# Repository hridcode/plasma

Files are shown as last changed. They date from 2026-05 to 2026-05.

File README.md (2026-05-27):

# Plasma

Plasma is an ortholinear staggered split keyboard that connects with BLE. It has an OLED display and rotary encoder as well for extra fun! With 6 columns and 5 rows, plus space keys right at the thumbs, what's not to love?

# Pictures

|Schematic (L)|Schematic (R)|PCB|Case|
|---|---|---|---|
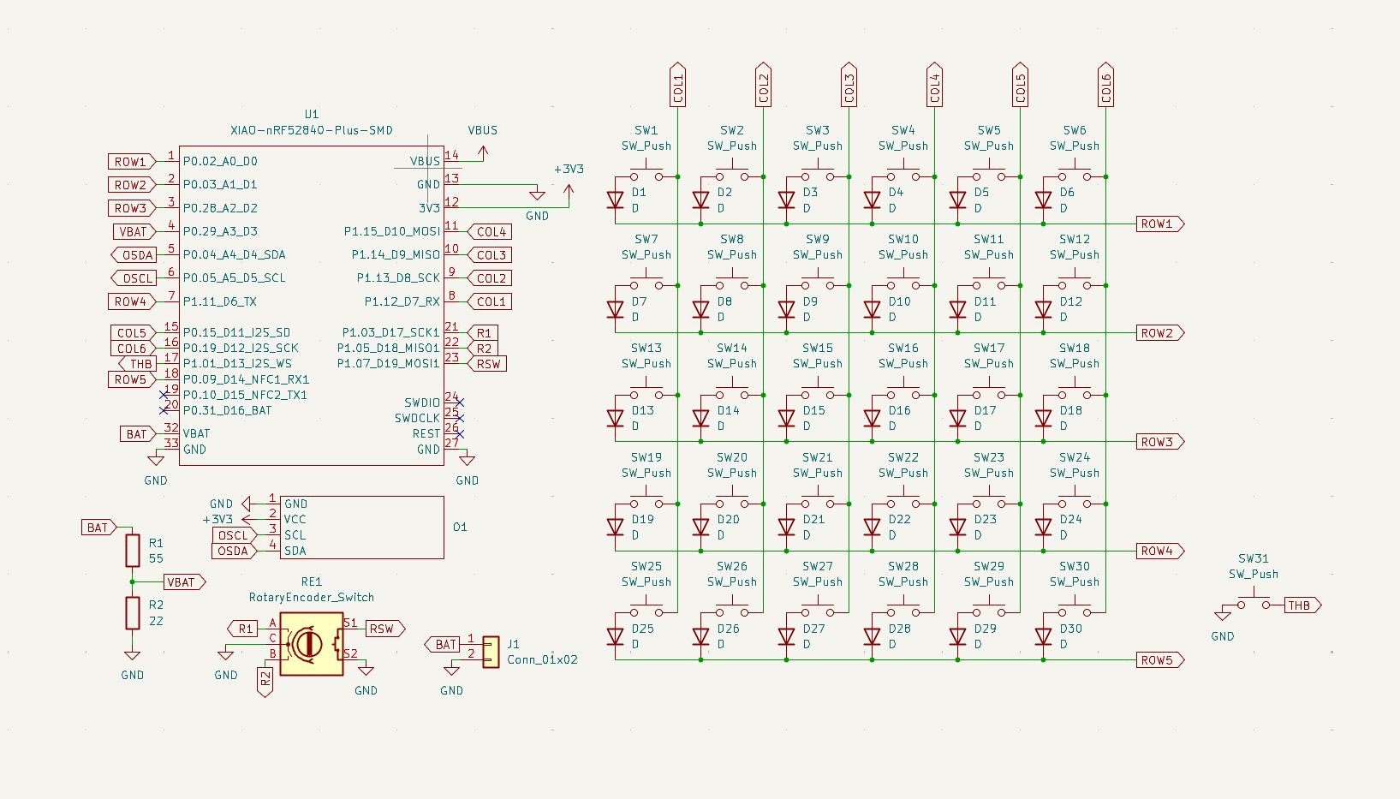
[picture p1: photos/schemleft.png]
Left schematic
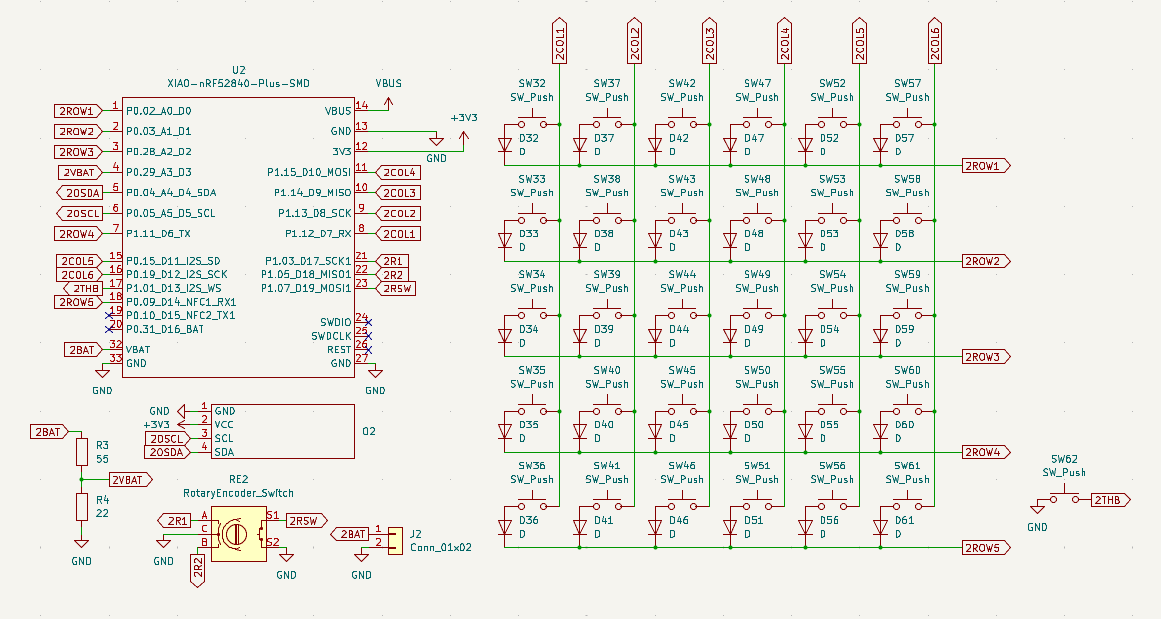
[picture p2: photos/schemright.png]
Right schematic
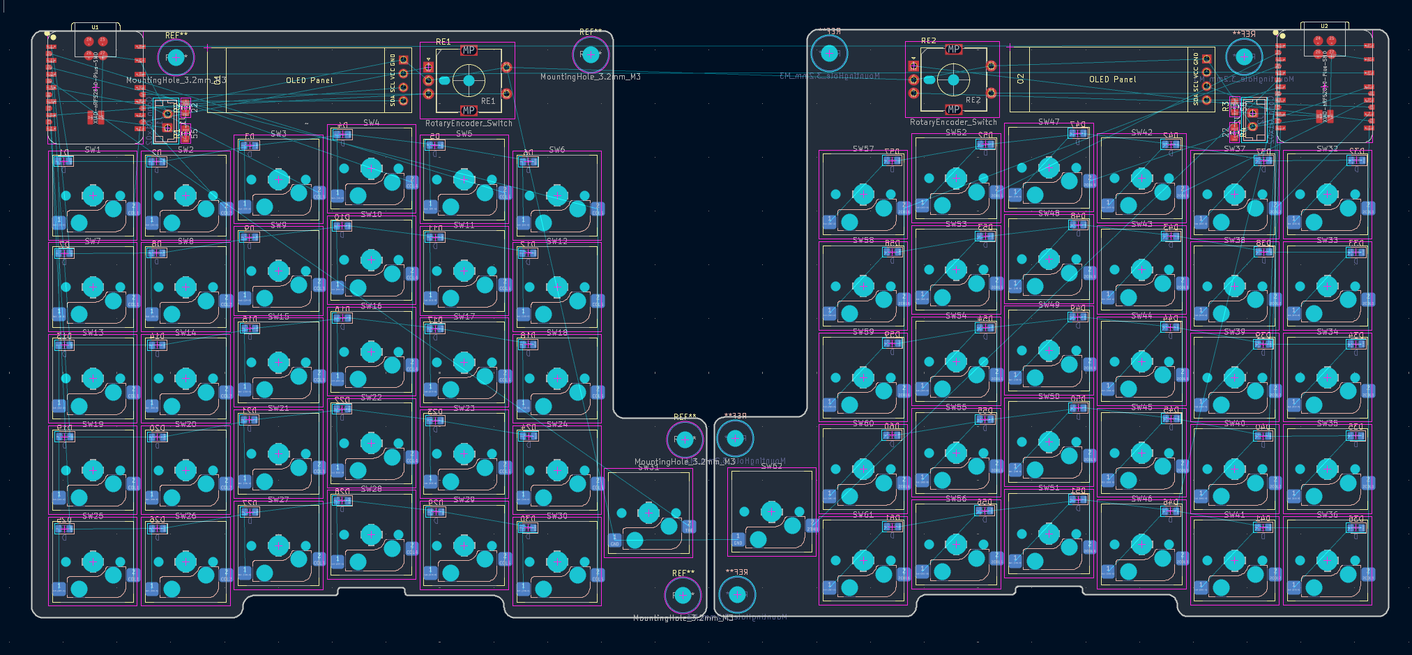
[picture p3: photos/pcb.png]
PCB
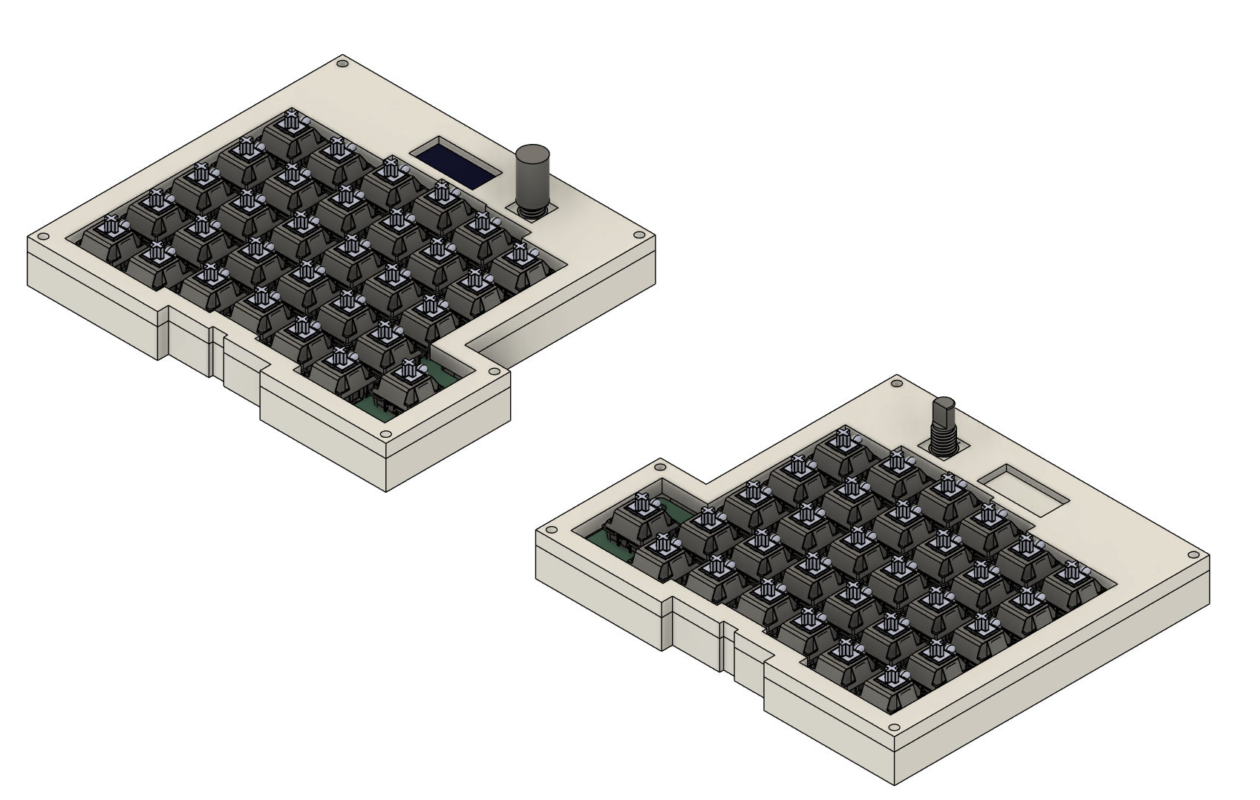
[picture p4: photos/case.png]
Case
|||||

# BOM

|Item|Quantity|Cost|Source|
|---|---|---|---|
|Seeed Studio XIAO nRF52840 Plus|2|20.80|https://www.seeedstudio.com/Seeed-Studio-XIAO-nRF52840-Plus-p-6359.html|
|Key switches|1|17.34|https://www.aliexpress.us/item/3256810602342636.html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|
YMDK ZDA black keycaps|1|16.94|https://www.aliexpress.us/item/3256808606272435.html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|
|EC11 rotary encoders|1|3.08|https://www.aliexpress.us/item/3256807457610925.html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|
|SSD1306 OLED displays|1|3.50|https://www.aliexpress.us/item/3256806882812437.html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|
|LiPo batteries|1|5.02|https://www.aliexpress.us/item/3256811857707355.html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|
|JST connectors|1|2.79|https://www.aliexpress.us/item/3256801462843682.html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|
|M3 inserts|1|0.73|https://www.aliexpress.com/ssr/300000512/BundleDeals2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|
|M3x16 screws|1|2.92|https://www.aliexpress.us/item/3256808523663879.html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|
|M3x6 screws|1|2.14|https://www.aliexpress.us/item/3256808523663879.html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|
|Hotswap sockets|1|3.89|https://www.aliexpress.com/ssr/300000512/BundleDeals2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
|PCBs|1|15.20|https://cart.jlcpcb.com/quote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|
|0805 resistors|1|6.50|https://www.aliexpress.us/item/3256805806582589.html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|
|3D printed case (from Printing Legion)|1|6.00|

Total: $120.17

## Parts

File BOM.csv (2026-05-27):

Item | Quantity | Cost | Source
Seeed Studio XIAO nRF52840 Plus | 2 | 20.80 | https://www.seeedstudio.com/Seeed-Studio-XIAO-nRF52840-Plus-p-6359.html
Key switches | 1 | 17.34 | https://www.aliexpress.us/item/3256810602342636.html?mp=1
YMDK ZDA black keycaps | 1 | 16.94 | https://www.aliexpress.us/item/3256808606272435.html?curPageLogUid=46jL7OyEjN3m
EC11 rotary encoders | 1 | 3.08 | https://www.aliexpress.us/item/3256807457610925.html?curPageLogUid=Gnz1vOJZ5LKS
SSD1306 OLED displays | 1 | 3.50 | https://www.aliexpress.us/item/3256806882812437.html?curPageLogUid=kfCFOX5XGs2T
LiPo batteries | 1 | 5.02 | https://www.aliexpress.us/item/3256811857707355.html
JST connectors | 1 | 2.79 | https://www.aliexpress.us/item/3256801462843682.html?curPageLogUid=LgkQ6isYab0G
M3 inserts | 1 | 0.73 | https://www.aliexpress.com/ssr/300000512/BundleDeals2?productIds=1005006967339727%3A12000038886016094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
M3x16 screws | 1 | 2.92 | https://www.aliexpress.us/item/3256808523663879.html?curPageLogUid=TUfYajctXH1A
M3x6 screws | 1 | 2.14 | https://www.aliexpress.us/item/3256808523663879.html?curPageLogUid=TUfYajctXH1A
Hotswap sockets | 1 | 3.89 | https://www.aliexpress.com/ssr/300000512/BundleDeals2?productIds=1005007052649640%3A12000039244942221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
PCBs | 1 | 15.20 | https://cart.jlcpcb.com/quote?stencilLayer=2&stencilWidth=253&stencilLength=110&stencilCounts=5&plateType=1
0805 SMD resistors | 1 | 6.50 | https://www.aliexpress.us/item/3256805806582589.html?curPageLogUid=6eeBEBX80vKN
3D printed case (from Printing Legion) | 1 | 6.00
Total |  | 120.17

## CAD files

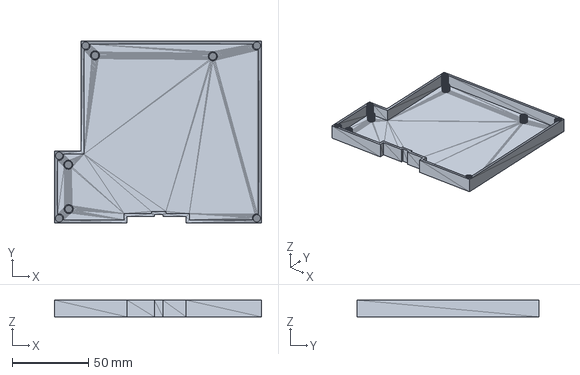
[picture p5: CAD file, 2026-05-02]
production/cad/BottomCase2.step
135.4 x 119.0 x 11.0 mm

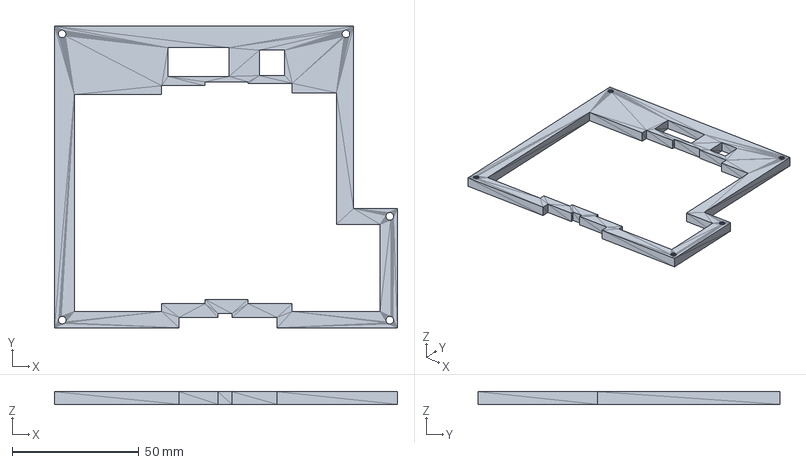
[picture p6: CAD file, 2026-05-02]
production/cad/TopCase.step
135.3 x 119.0 x 5.00 mm

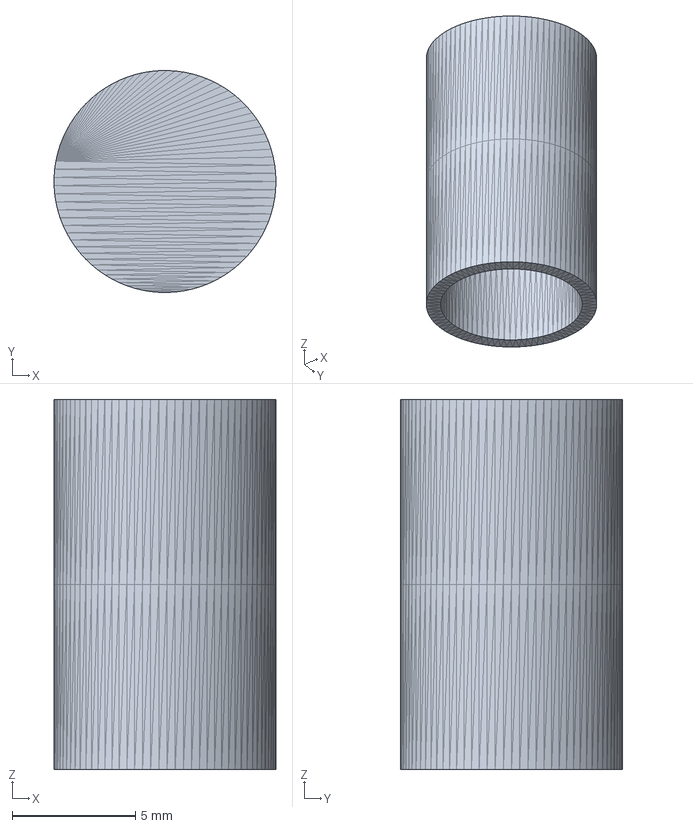
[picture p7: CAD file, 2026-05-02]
production/cad/EncoderKnob.step
9.00 x 9.00 x 15.0 mm

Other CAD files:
production/cad/BottomCase.step
production/cad/TopCase2.step

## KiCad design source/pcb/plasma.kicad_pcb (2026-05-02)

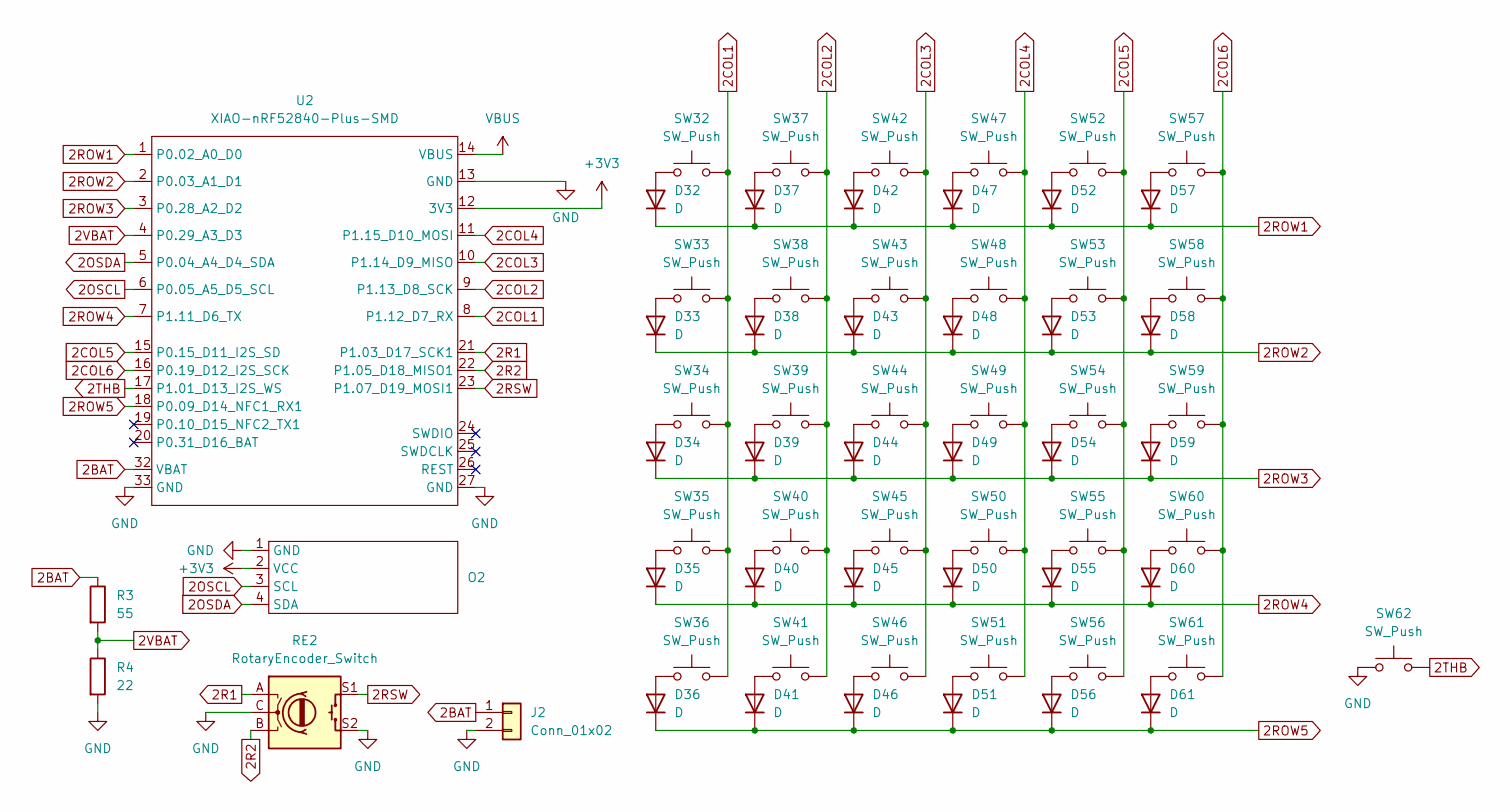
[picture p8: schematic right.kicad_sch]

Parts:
D32, D33, D34, D35, D36, D37, D38, D39, D40, D41, D42, D43, D44, D45, D46, D47, D48, D49, D50, D51, D52, D53, D54, D55, D56, D57, D58, D59, D60, D61: D; D_0805_2012Metric_Pad1.15x1.40mm_HandSolder
J2: Conn_01x02; JST_EH_B2B-EH-A_1x02_P2.50mm_Vertical
O2: SSD1306-4pin-0.91
R3: 55; R_0805_2012Metric_Pad1.20x1.40mm_HandSolder
R4: 22; R_0805_2012Metric_Pad1.20x1.40mm_HandSolder
RE2: RotaryEncoder_Switch; RotaryEncoder_Alps_EC11E-Switch_Vertical_H20mm_MountingHoles
SW32, SW33, SW34, SW35, SW36, SW37, SW38, SW39, SW40, SW41, SW42, SW43, SW44, SW45, SW46, SW47, SW48, SW49, SW50, SW51, SW52, SW53, SW54, SW55, SW56, SW57, SW58, SW59, SW60, SW61, SW62: SW_Push; SW_MX_HotSwap_THT
U2: XIAO-nRF52840-Plus-SMD

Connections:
2BAT: J2.1, R3.1, U2.32 (VBAT)
2COL1: SW32.2, SW33.2, SW34.2, SW35.2, SW36.2, U2.8 (P1.12_D7_RX)
2COL2: SW37.2, SW38.2, SW39.2, SW40.2, SW41.2, U2.9 (P1.13_D8_SCK)
2COL3: SW42.2, SW43.2, SW44.2, SW45.2, SW46.2, U2.10 (P1.14_D9_MISO)
2COL4: SW47.2, SW48.2, SW49.2, SW50.2, SW51.2, U2.11 (P1.15_D10_MOSI)
2COL5: SW52.2, SW53.2, SW54.2, SW55.2, SW56.2, U2.15 (P0.15_D11_I2S_SD)
2COL6: SW57.2, SW58.2, SW59.2, SW60.2, SW61.2, U2.16 (P0.19_D12_I2S_SCK)
2OSCL: O2.3 (SCL), U2.6 (P0.05_A5_D5_SCL)
2OSDA: O2.4 (SDA), U2.5 (P0.04_A4_D4_SDA)
2R1: RE2.A, U2.21 (P1.03_D17_SCK1)
2R2: RE2.B, U2.22 (P1.05_D18_MISO1)
2ROW1: D32.1 (K), D37.1 (K), D42.1 (K), D47.1 (K), D52.1 (K), D57.1 (K), U2.1 (P0.02_A0_D0)
2ROW2: D33.1 (K), D38.1 (K), D43.1 (K), D48.1 (K), D53.1 (K), D58.1 (K), U2.2 (P0.03_A1_D1)
2ROW3: D34.1 (K), D39.1 (K), D44.1 (K), D49.1 (K), D54.1 (K), D59.1 (K), U2.3 (P0.28_A2_D2)
2ROW4: D35.1 (K), D40.1 (K), D45.1 (K), D50.1 (K), D55.1 (K), D60.1 (K), U2.7 (P1.11_D6_TX)
2ROW5: D36.1 (K), D41.1 (K), D46.1 (K), D51.1 (K), D56.1 (K), D61.1 (K), U2.18 (P0.09_D14_NFC1_RX1)
2RSW: RE2.S1, U2.23 (P1.07_D19_MOSI1)
2THB: SW62.2, U2.17 (P1.01_D13_I2S_WS)
2VBAT: R3.2, R4.1, U2.4 (P0.29_A3_D3)
+3V3: O2.2 (VCC), U2.12 (3V3); also elsewhere on the board
GND: J2.2, O2.1 (GND), R4.2, RE2.C, RE2.S2, SW62.1, U2.13 (GND), U2.27 (GND), U2.33 (GND); also elsewhere on the board
unnamed: D32.2 (A), SW32.1
unnamed: D33.2 (A), SW33.1
unnamed: D34.2 (A), SW34.1
unnamed: D35.2 (A), SW35.1
unnamed: D36.2 (A), SW36.1
unnamed: D37.2 (A), SW37.1
unnamed: D38.2 (A), SW38.1
unnamed: D39.2 (A), SW39.1
unnamed: D40.2 (A), SW40.1
unnamed: D41.2 (A), SW41.1
unnamed: D42.2 (A), SW42.1
unnamed: D43.2 (A), SW43.1
unnamed: D44.2 (A), SW44.1
unnamed: D45.2 (A), SW45.1
unnamed: D46.2 (A), SW46.1
unnamed: D47.2 (A), SW47.1
unnamed: D48.2 (A), SW48.1
unnamed: D49.2 (A), SW49.1
unnamed: D50.2 (A), SW50.1
unnamed: D51.2 (A), SW51.1
unnamed: D52.2 (A), SW52.1
unnamed: D53.2 (A), SW53.1
unnamed: D54.2 (A), SW54.1
unnamed: D55.2 (A), SW55.1
unnamed: D56.2 (A), SW56.1
unnamed: D57.2 (A), SW57.1
unnamed: D58.2 (A), SW58.1
unnamed: D59.2 (A), SW59.1
unnamed: D60.2 (A), SW60.1
unnamed: D61.2 (A), SW61.1
VBUS: U2.14 (VBUS); also elsewhere on the board

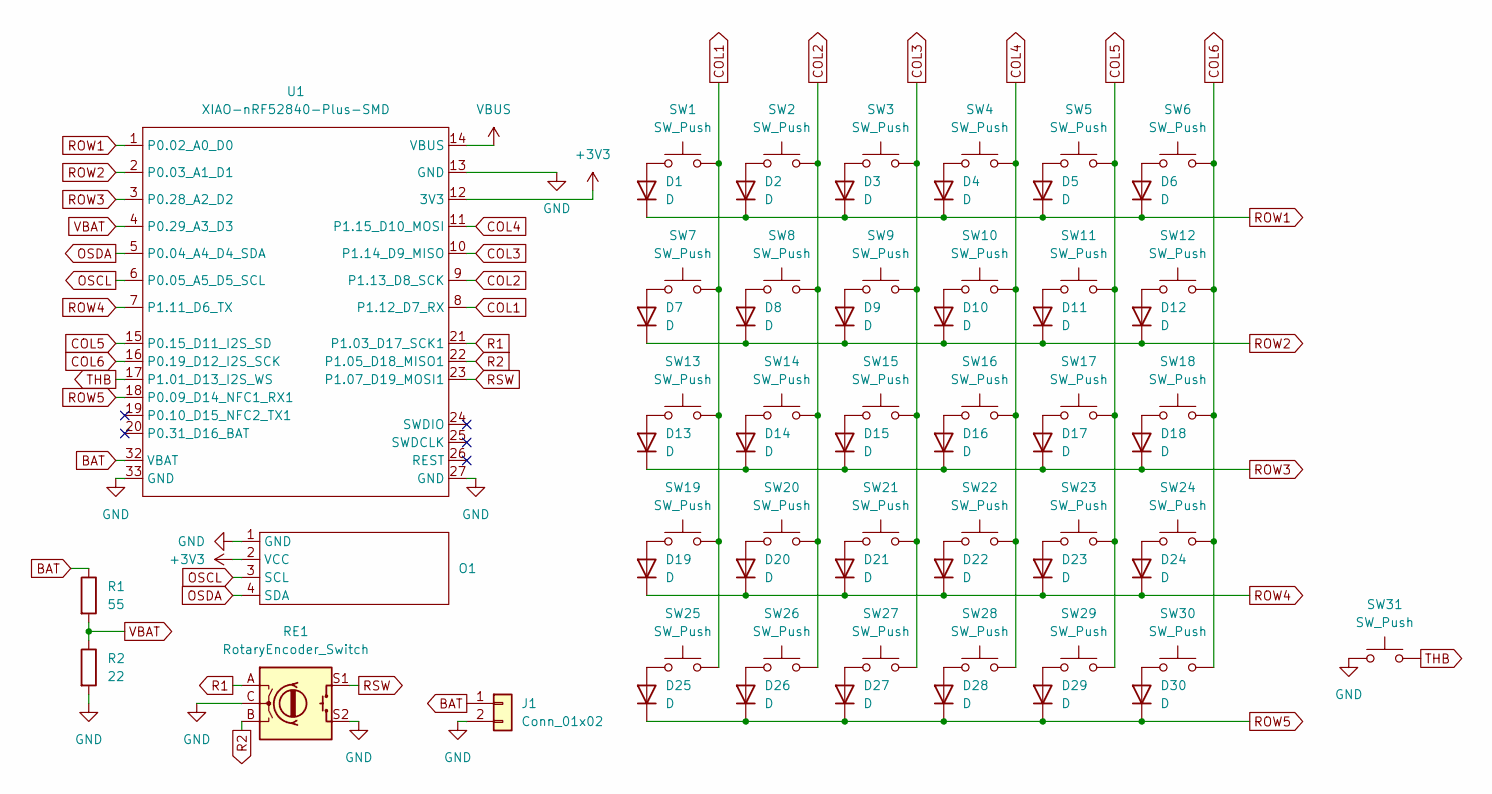
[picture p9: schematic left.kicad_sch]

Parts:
D1, D2, D3, D4, D5, D6, D7, D8, D9, D10, D11, D12, D13, D14, D15, D16, D17, D18, D19, D20, D21, D22, D23, D24, D25, D26, D27, D28, D29, D30: D; D_0805_2012Metric_Pad1.15x1.40mm_HandSolder
J1: Conn_01x02; JST_EH_B2B-EH-A_1x02_P2.50mm_Vertical
O1: SSD1306-4pin-0.91
R1: 55; R_0805_2012Metric_Pad1.20x1.40mm_HandSolder
R2: 22; R_0805_2012Metric_Pad1.20x1.40mm_HandSolder
RE1: RotaryEncoder_Switch; RotaryEncoder_Alps_EC11E-Switch_Vertical_H20mm_MountingHoles
SW1, SW2, SW3, SW4, SW5, SW6, SW7, SW8, SW9, SW10, SW11, SW12, SW13, SW14, SW15, SW16, SW17, SW18, SW19, SW20, SW21, SW22, SW23, SW24, SW25, SW26, SW27, SW28, SW29, SW30, SW31: SW_Push; SW_MX_HotSwap_THT
U1: XIAO-nRF52840-Plus-SMD

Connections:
+3V3: O1.2 (VCC), U1.12 (3V3); also elsewhere on the board
BAT: J1.1, R1.1, U1.32 (VBAT)
COL1: SW1.2, SW7.2, SW13.2, SW19.2, SW25.2, U1.8 (P1.12_D7_RX)
COL2: SW2.2, SW8.2, SW14.2, SW20.2, SW26.2, U1.9 (P1.13_D8_SCK)
COL3: SW3.2, SW9.2, SW15.2, SW21.2, SW27.2, U1.10 (P1.14_D9_MISO)
COL4: SW4.2, SW10.2, SW16.2, SW22.2, SW28.2, U1.11 (P1.15_D10_MOSI)
COL5: SW5.2, SW11.2, SW17.2, SW23.2, SW29.2, U1.15 (P0.15_D11_I2S_SD)
COL6: SW6.2, SW12.2, SW18.2, SW24.2, SW30.2, U1.16 (P0.19_D12_I2S_SCK)
GND: J1.2, O1.1 (GND), R2.2, RE1.C, RE1.S2, SW31.1, U1.13 (GND), U1.27 (GND), U1.33 (GND); also elsewhere on the board
unnamed: D1.2 (A), SW1.1
unnamed: D2.2 (A), SW2.1
unnamed: D3.2 (A), SW3.1
unnamed: D4.2 (A), SW4.1
unnamed: D5.2 (A), SW5.1
unnamed: D6.2 (A), SW6.1
unnamed: D7.2 (A), SW7.1
unnamed: D8.2 (A), SW8.1
unnamed: D9.2 (A), SW9.1
unnamed: D10.2 (A), SW10.1
unnamed: D11.2 (A), SW11.1
unnamed: D12.2 (A), SW12.1
unnamed: D13.2 (A), SW13.1
unnamed: D14.2 (A), SW14.1
unnamed: D15.2 (A), SW15.1
unnamed: D16.2 (A), SW16.1
unnamed: D17.2 (A), SW17.1
unnamed: D18.2 (A), SW18.1
unnamed: D19.2 (A), SW19.1
unnamed: D20.2 (A), SW20.1
unnamed: D21.2 (A), SW21.1
unnamed: D22.2 (A), SW22.1
unnamed: D23.2 (A), SW23.1
unnamed: D24.2 (A), SW24.1
unnamed: D25.2 (A), SW25.1
unnamed: D26.2 (A), SW26.1
unnamed: D27.2 (A), SW27.1
unnamed: D28.2 (A), SW28.1
unnamed: D29.2 (A), SW29.1
unnamed: D30.2 (A), SW30.1
OSCL: O1.3 (SCL), U1.6 (P0.05_A5_D5_SCL)
OSDA: O1.4 (SDA), U1.5 (P0.04_A4_D4_SDA)
R1: RE1.A, U1.21 (P1.03_D17_SCK1)
R2: RE1.B, U1.22 (P1.05_D18_MISO1)
ROW1: D1.1 (K), D2.1 (K), D3.1 (K), D4.1 (K), D5.1 (K), D6.1 (K), U1.1 (P0.02_A0_D0)
ROW2: D7.1 (K), D8.1 (K), D9.1 (K), D10.1 (K), D11.1 (K), D12.1 (K), U1.2 (P0.03_A1_D1)
ROW3: D13.1 (K), D14.1 (K), D15.1 (K), D16.1 (K), D17.1 (K), D18.1 (K), U1.3 (P0.28_A2_D2)
ROW4: D19.1 (K), D20.1 (K), D21.1 (K), D22.1 (K), D23.1 (K), D24.1 (K), U1.7 (P1.11_D6_TX)
ROW5: D25.1 (K), D26.1 (K), D27.1 (K), D28.1 (K), D29.1 (K), D30.1 (K), U1.18 (P0.09_D14_NFC1_RX1)
RSW: RE1.S1, U1.23 (P1.07_D19_MOSI1)
THB: SW31.2, U1.17 (P1.01_D13_I2S_WS)
VBAT: R1.2, R2.1, U1.4 (P0.29_A3_D3)
VBUS: U1.14 (VBUS); also elsewhere on the board

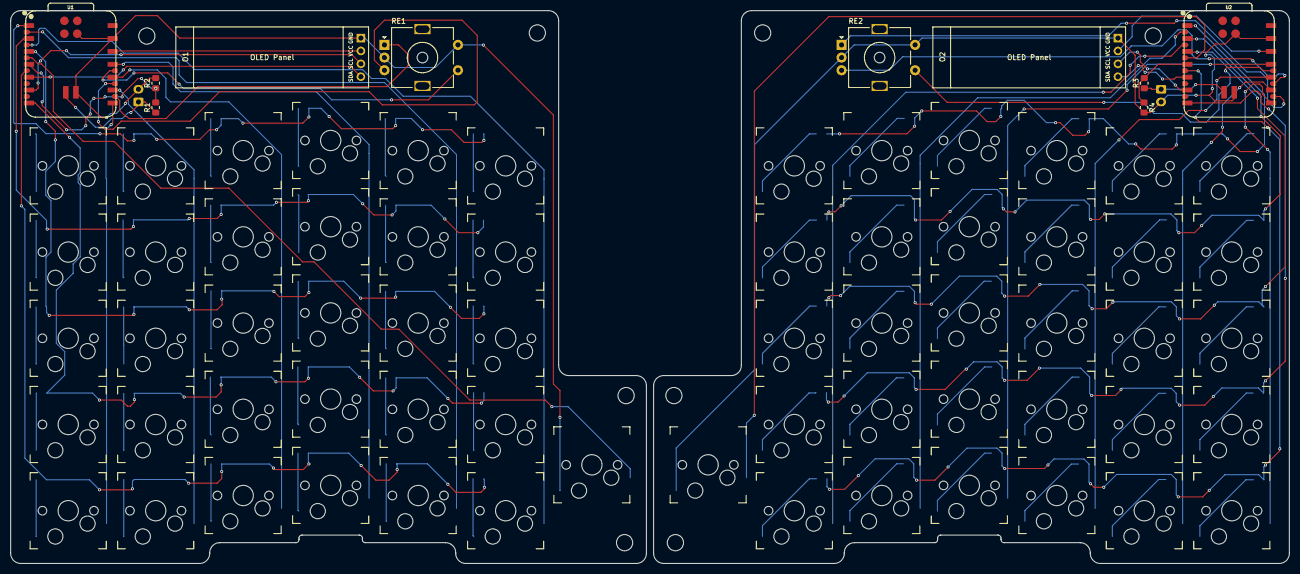
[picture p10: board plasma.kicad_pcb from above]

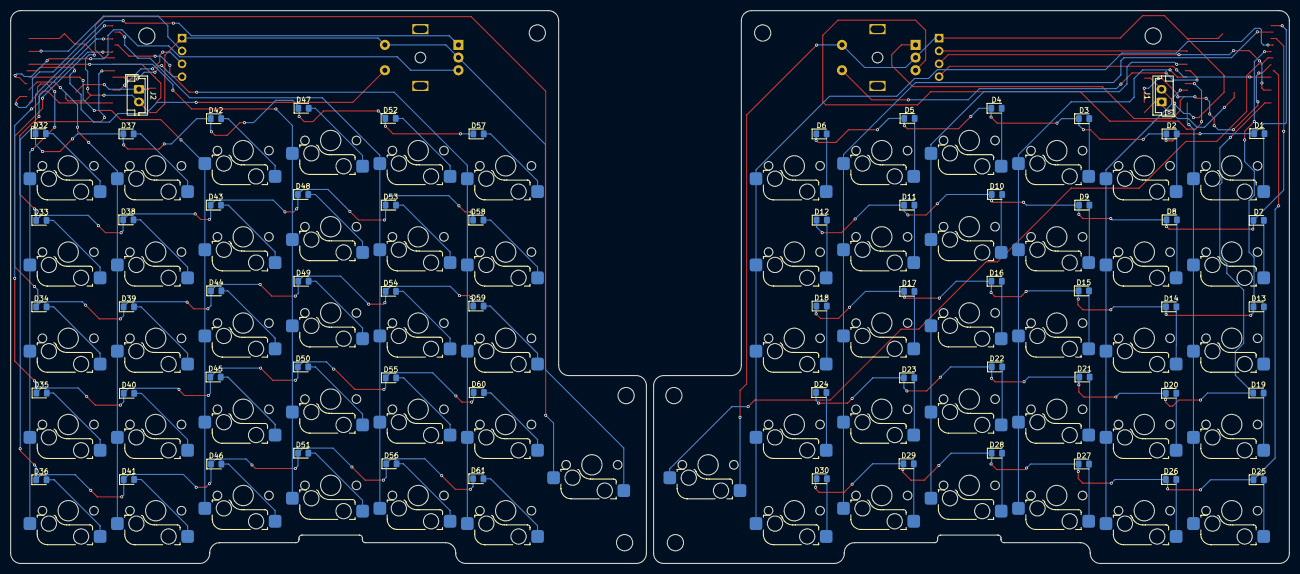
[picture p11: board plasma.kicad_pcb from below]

Board: 2 copper layers, 252.1 x 109.0 mm, 134 parts (62 on the bottom side), 101 nets.

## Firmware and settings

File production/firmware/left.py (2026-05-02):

print("Starting")

import board, busio

from kmk.kmk_keyboard import KMKKeyboard
from kmk.keys import KC
from kmk.scanners import DiodeOrientation
from kmk.modules.layers import Layers
from kmk.modules.split import Split, SplitType, SplitSide
from kmk.hid import HIDModes
from kmk.extensions.display import Display, TextEntry, ImageEntry
from kmk.extensions.display.ssd1306 import SSD1306
from kmk.modules.encoder import EncoderHandler
from kmk.extensions.media_keys import MediaKeys
from kmk.scanners import gpio

keyboard = KMKKeyboard()

layers = Layers()
split = Split(split_type=SplitType.BLE, split_side=SplitSide.LEFT)
i2c_bus = busio.I2C(board.GP4, board.GP5)

driver = SSD1306(
    i2c=i2c_bus,
    device_address=0x3C,
)

display = Display(
    display=driver,
    width=128
    height=64,
    brightness=0.8,
    brightness_step=0.1,
    dim_time=60,
    dim_target=0.1,
    off_time=180,
    powersave_dim_time=30,
    powersave_dim_target=0.1,
    powersave_off_time=90
)

display.entries = [
    TextEntry(text="the best keyboard", x=0, y=0)
]

keyboard.modules.append(layers)
keyboard.extensions.append(display)
keyboard.extensions.append(MediaKeys())

encoder_handler = EncoderHandler()
encoder_handler.pins = [(board.GP17, board.GP18, board.GP19),]
encoder_handler.map = [((KC.AUDIO_VOL_DOWN,KC.AUDIO_VOL_UP,KC.AUDIO_MUTE),),(KC.BRIGHTNESS_DOWN,KC.BRIGHTNESS_UP,KC.NO)]
keyboard.extensions.append(encoder_handler)
keyboard.modules.append(split)

keyboard.row_pins = (
    board.GP0, board.GP1, board.GP2, board.GP6, board.GP14
)

keyboard.col_pins = (
    board.GP7, board.GP8, board.GP9, board.GP10, board.GP11, board.GP12
)

keyboard.diode_orientation = DiodeOrientation.COL2ROW

MO1 = KC.MO(1)

keyboard.keymap = [
    [
        KC.ESC, KC.N1, KC.N2, KC.N3, KC.N4, KC.N5,
        KC.TAB, KC.Q, KC.W, KC.E, KC.R, KC.T,
        KC.CAPS, KC.A, KC.S, KC.D, KC.F, KC.G,
        KC.LSHIFT, KC.Z, KC.X, KC.C, KC.V, KC.B,
        KC.LCTL, KC.LGUI, KC.LALT, KC.FN, KC.RCTL, MO1
    ],
    [
        KC.F1, KC.F2, KC.F3, KC.F4, KC.F5, KC.F6,
        KC.TAB, KC.NO, KC.NO, KC.NO, KC.NO, KC.DEL,
        KC.GRAVE, KC.NO, KC.NO, KC.NO, KC.PGUP,
        KC.NO, KC.NO, KC.NO, KC.NO, KC.PGDN,
        KC.LCTL, KC.LGUI, KC.LALT, KC.FN, KC.END, KC.NO
    ]
]

thumb = gpio.GPIOInputPin(13)
keyboard.coord_mapping = {
    thumb: KC.SPACE
}

if __name__ == '__main__':
    keyboard.go()
    keyboard.go(hid_type=HIDModes.BLE, ble_name='Plasma')

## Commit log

2026-05-02 Added production, source, BOM, and README.md
    [BOM.csv, BottomCase.step, BottomCase2.step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]
2026-05-02 Updated BOM
    [BOM.csv]
